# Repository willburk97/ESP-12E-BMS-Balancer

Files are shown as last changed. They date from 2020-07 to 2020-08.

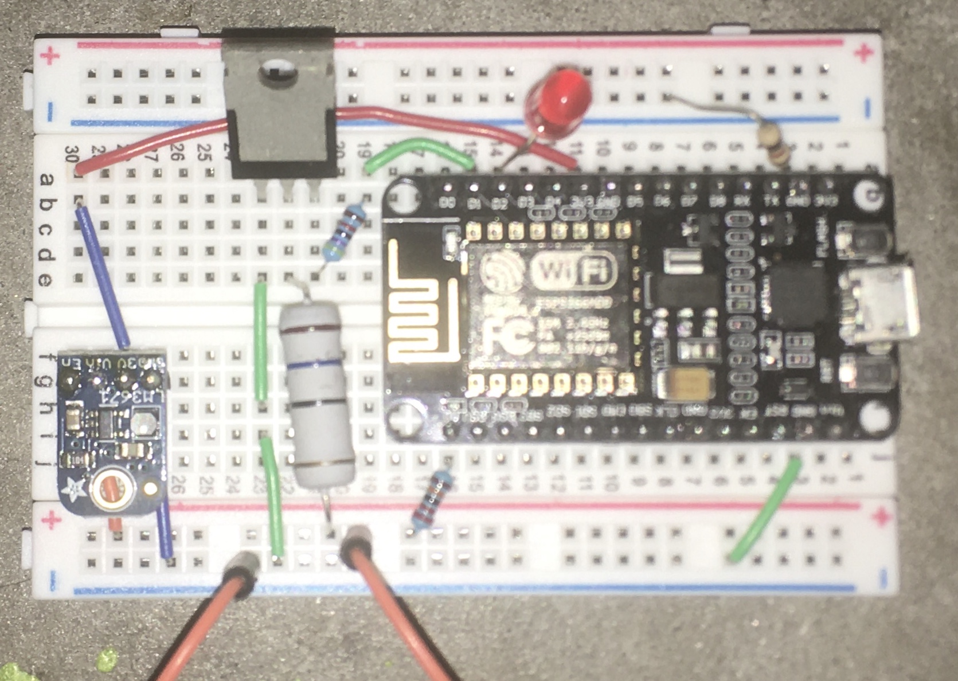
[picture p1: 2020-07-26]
DD4AA2B9-804A-49C7-B6A8-159DF102B3EF.jpeg

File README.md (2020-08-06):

# ESP-12E-BMS-Balancer
li-ion BMS / Balancer made of multiple NodeMCU ESP-12E (one per cell) using Adafruit io to store/track/trend each cell's voltage.

I used an LM3671 from adafruit to power the 3.3v in of the ESP-12E directly because my NodeMCU version uses an LDO regulator which drops half 
a volt or so. I wanted my ESP-12E to be able to continue monitoring the cell all the way down to 2.4 volts or so. The LDO wouldn't allow that.

I used an IRFZ44 mosfet (driven by D1 through a resistor) to connect a 16 ohm / 3W resistor to the batery input.  At a ~4VDC input this'd be 250mA and 1W worth of drain.  
The code leads to a battery drain (mosfet) duty cycle of about 80%, so technically about 800mW of drain.  While draining, the resistor can be touched momentarily but is 
hot enough to burn you.  It was not hot enough to melt my temporary breadboard or the wires/components nearby.

As mentioned in the code, A0 on the NodeMCU has a built in voltage divider of 100k:220k ohms.  This enables you to simply jumper from A0 to the battery in with a 220k 
resistor (for li-ion) which creates a 100k:440k voltage divider, which is a ratio of 1:5.4 

In case the search function checks the readme for codewords, here're some:
NodeMCU, ESP12, ESP-12, ESP12E, ESP-12E, ESP8266, Battery Management System, Balance, lithium, pack

I added the code from an ESP32 I was testing as well.  I coded it to monitor battery4 (and the code would have to be adjusted to match the battery it is connected to.)
This code was used before I added the staleData code you'll see in the ESP12 code.  The side effect of not having the staleData code is that if a battery is low and then
disconnected from the internet, this ESP will attempt to drain it's battery down to that last known voltage...ignoring the fact that the last known voltage could be very
very old.  This is handy for testing and/or forcing a single cell to a certain voltage but not ideal for regular use or as a reliable BMS. (Basically, I think the staleData
code is important, I just never implemented it in the ESP32 code.)

Added Schematic and Board layouts for two different ESP-12E BMS styles. One with the LM3671 from Adafruit and one without.  It can be used without the Adafruit board, but
somewhere around 3.0v the ESP-12E will turn off because of the inherent voltage drop across the LDO voltage regulator. The 'Low Voltage' version uses the Adafruit buck
converter, the other does not.  

I haven NOT double checked the schematic for accuracy nor have I printed the PCB to test it out.  Please sanity check them both before use.
I used Autodesk Eagle for the schematic and board layout.

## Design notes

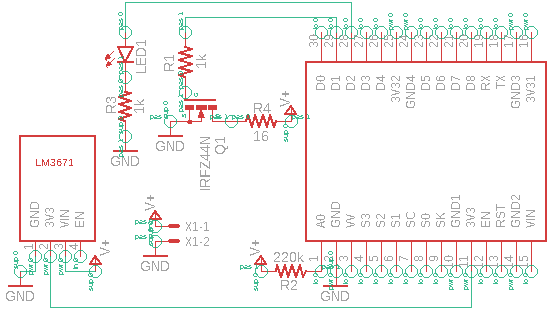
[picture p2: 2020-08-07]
ESP12E BMS Low Voltage Schematic.png

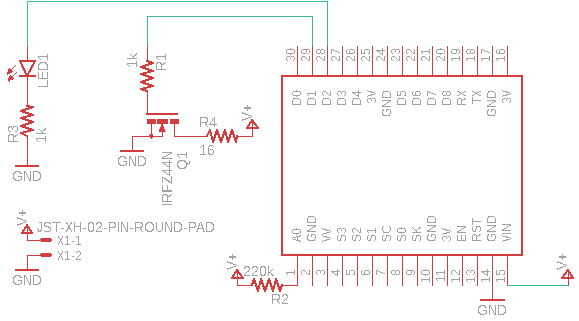
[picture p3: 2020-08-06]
ESP12E_BMS.png

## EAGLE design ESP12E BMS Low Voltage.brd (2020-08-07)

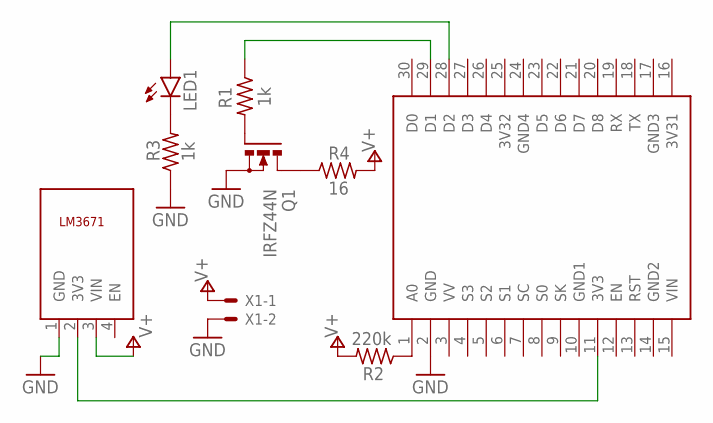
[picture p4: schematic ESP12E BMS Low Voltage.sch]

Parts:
LED1: TLLR4400; LED3MM
Q1: IRFZ44N; TO220BH
R1, R3: 1k; 0204/7
R2: 220k; 0204/7
R4: 16; P0613/15
U$1: NODEMCU
U$2: LM3671
X1: JST-XH-02-PIN-ROUND-PAD; JST-XH-02-PACKAGE-ROUND-PAD

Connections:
3V31: U$1.16 (3V31)
3V32: U$1.25 (3V32)
GND: Q1.S, R3.1, U$1.2 (GND), U$2.1 (GND), X1.2
GND1: U$1.10 (GND1)
GND2: U$1.14 (GND2)
GND3: U$1.17 (GND3)
GND4: U$1.24 (GND4)
unnamed: LED1.K (C), R3.2
unnamed: Q1.G, R1.2
unnamed: Q1.D, R4.1
unnamed: R1.1, U$1.29 (D1)
unnamed: LED1.A, U$1.28 (D2)
unnamed: R2.1, U$1.1 (A0)
unnamed: U$1.11 (3V3), U$2.2 (3V3)
V+: R2.2, R4.2, U$2.3 (VIN), X1.1

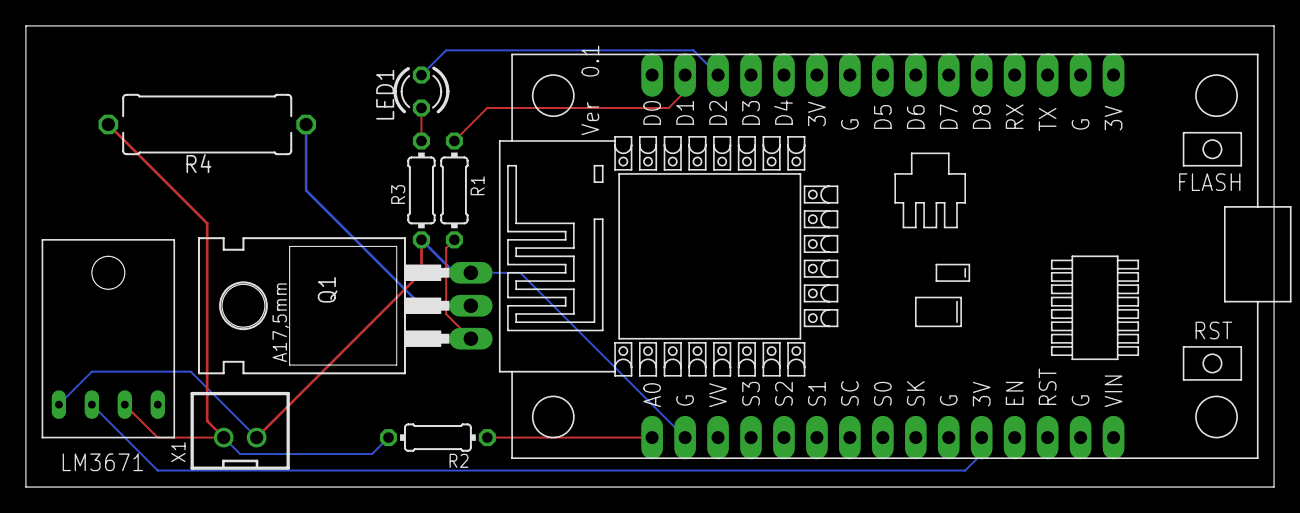
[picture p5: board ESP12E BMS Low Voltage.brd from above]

Board: 2 copper layers, 96.2 x 35.5 mm, 9 parts (0 on the bottom side), 9 nets.

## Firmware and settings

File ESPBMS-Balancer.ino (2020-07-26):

// Tutorial Link: https://learn.adafruit.com/adafruit-io-basics-analog-input
//
// Adafruit invests time and resources providing (...a small part of...) this open source code.
// Please support Adafruit and open source hardware by purchasing
// products from Adafruit!
//
// (The adafruit io portion of this was...) Written by Todd Treece for Adafruit Industries
// Copyright (c) 2016 Adafruit Industries
// Licensed under the MIT license.
//
// All text above must be included in any redistribution.

// All other code below was written by William Burk for himself or copied and pasted from somewhere else. (Sorry Todd for making a mess of your code.)


#define IO_USERNAME "Your adafruit username here"
#define IO_KEY "your adafruit key here"
#define WIFI_SSID "yourSSID"
#define WIFI_PASS "yourwifipassword"
#include "AdafruitIO_WiFi.h"
AdafruitIO_WiFi io(IO_USERNAME, IO_KEY, WIFI_SSID, WIFI_PASS);

#define analogIn A0  // The NodeMCU ESP12 has a built in 100k:220k Voltage divider so I just jumpered A0 to my battery input with a 220k resistor so it's a 1:5.4 ratio.
      // Note: Vin on the NodeMCU uses a LDO voltage regulator which wouldn't allow me to drain (or use) my battery as low as I wanted. So I ended up using the adafruit
      // LM3671 3.3v buck converter and feeding the 3.3 input on the NodeMCU directly.
#define LEDPin D0    //This is the builtin LED on the NodeMCU, it monitors communications.  On at first and then intermittent flash for comms.
#define mosfetPin D1  // This goes high to activate the mosfet (IRFZ44N) I use to discharge the battery through a 16ohm/3w resistor (4.0v li-ion, 250mA, 1 W drain)
#define dischargeLEDpin D2  //This LED shows me when the battery is being drained
float sensorValue = 0;
float allowedCellDiff = 0.05;
float lowBatt = 10;
bool dischargeState = false;
int sensorInt;
unsigned long lastTxTime = 0;

int thisBatt = 1;   // 0 referenced number of the cell this ESP12 is monitoring. This code is for cell 2.

// You have to manually change the code for each cell in the 'pack.' (This is cell 2 so we're not monitoring it's time.)
unsigned long battTime;
//unsigned long battTime2;
unsigned long battTime3;
unsigned long battTime4;

int staleData = 0;  // Binary coded stale data monitor. 0000 means current data. 0100 means Cell 3 is stale. (i.e. no updates getting to/from adafruit io)


unsigned int minTxTime = 60000;
unsigned int sampleTime = 1000;
String debugText = "0.00 0.00 0.00 0.00 ";
unsigned int dischargeTime = 0;
int i;
float battVolt[4];

AdafruitIO_Feed *espbattery = io.feed("espbattery");
AdafruitIO_Feed *espbattery2 = io.feed("espbattery2");
AdafruitIO_Feed *espbattery3 = io.feed("espbattery3");
AdafruitIO_Feed *espbattery4 = io.feed("espbattery4");
//AdafruitIO_Feed *debugtext = io.feed("debug-text");  // Activate this on one ESP12 and you'll have a quick text reference for each cell voltage.

// **You have to manually change the code for each cell in the 'pack.' (This is cell 2 so we upload it's draining status.) You only have to adjust what's in quotes.
AdafruitIO_Feed *battdischarge = io.feed("battdischarge2");

//AdafruitIO_Feed *battdischargetime = io.feed("battdischargetime2");   // This would enable us to monitor how much a cell has been drained. I turned it off to minimize updates to adafruit io.
// The above must be updated to mactch the cell connected to this ESP12.

void setup() {
  pinMode(LEDPin, OUTPUT);
  pinMode(mosfetPin, OUTPUT);
  pinMode(dischargeLEDpin, OUTPUT);
  // start the serial connection
  Serial.begin(115200);

  // connect to io.adafruit.com
  Serial.print("Connecting to Adafruit IO");
  io.connect();

  // wait for a connection
  while(io.status() < AIO_CONNECTED) {
    Serial.print(".");
    delay(500);
  }

  // we are connected
  Serial.println();
  Serial.println(io.statusText());

// You have to manually change the code for each cell in the 'pack.' (This is cell 2 so we're not requesting it's voltage from adafruit.)
  espbattery->onMessage(getBatt);
//  espbattery2->onMessage(getBatt2);
  espbattery3->onMessage(getBatt3);
  espbattery4->onMessage(getBatt4);

//These force an initial update from adafruit io.
  espbattery->get();
//  espbattery2->get();
  espbattery3->get();
  espbattery4->get();
}

void loop() {
  io.run();

  updateVoltage();

  lowBatt = 10;
  for (i=0;i<4;i++) {
    if (battVolt[i] < lowBatt) { lowBatt = battVolt[i]; }
  }

  digitalWrite(LEDPin, LOW);
  delay(30);
  digitalWrite(LEDPin, HIGH);
  
      debugText = "";
      for (i=0;i<4;i=i+1) {
        Serial.print(battVolt[i]); Serial.print(" ");
        debugText += String(battVolt[i]);
        debugText += String(" ");
      }
      Serial.println();
  if(millis() > lastTxTime + minTxTime)
  {
    lastTxTime = millis();
    Serial.println("Sent Last");

    if (battVolt[thisBatt] <= lowBatt || battVolt[thisBatt] < 3.0) {
      digitalWrite(mosfetPin, false);
      digitalWrite(dischargeLEDpin, false);
      dischargeState = false;
      Serial.println("Battery not Draining");
    }
    
// You have to manually change the code for each cell in the 'pack.' (This is cell 2 so we save it's voltage to adafruit io.)
    espbattery2->save(sensorValue);
//Enable this on one ESP12 for easy text readable battery voltages on adafruit io.    
//    debugtext->save(debugText);
//The two below are actually universal and don't have to be updated based on cell.
    battdischarge->save(dischargeState);
//    battdischargetime->save(dischargeTime);   // If you have the adafruit io bandwidth this is a nice way to keep track of each cells drain time.  The cell with the lowest time is the weakest.
    
    digitalWrite(LEDPin, LOW);
    delay(100); // just to be safe

// I originally used these to force a read of the adafruit io every tx loop. These are unnecessary since the onMessage code gives us the updates as soon as adafruit io gets them. 
// Note: You cannot use these if you want the battTime code to work as these force the battTime to update every time they're run. (And these just load whatever old data exists.)
//    espbattery->get();
//    espbattery2->get();
//    espbattery3->get();
//    espbattery4->get();

    digitalWrite(LEDPin, HIGH);

  }
    
  if (dischargeState) { dischargeTime++; }
  
  if ((millis() > 30000) && (battVolt[thisBatt] > (lowBatt + allowedCellDiff)) && (battVolt[thisBatt] > 3.0) && (staleData == 0)) {
    digitalWrite(mosfetPin, true);
    digitalWrite(dischargeLEDpin, true);
    dischargeState = true;
    Serial.println("Battery Draining");
  }
  
  delay(sampleTime-150);

}

void updateVoltage() {

  digitalWrite(mosfetPin, false);  // Turn off the mosfet/resistor load so we can read an accurate 'unloaded' voltage.
  
  int sensorInt = 0;
  for (i=0;i<10;i=i+1) {
    delay(15);
    sensorInt = sensorInt + analogRead(analogIn);
  }
  sensorInt = sensorInt / 10;
  sensorValue = (sensorInt * 5.44) / 1024;  //was 5.31
  sensorInt = (sensorValue * 100);     // Round to two decimal places...
  sensorValue = sensorInt;
  sensorValue = sensorValue / 100;
  
  battVolt[thisBatt] = sensorValue;
  
// ***You have to manually change the code for each cell in the 'pack.' (This is cell 2 so we're not monitoring it's staleness/time.)
  if ((battTime + 80000) < millis()){ staleData = (staleData | (0x1));  }
//  if ((battTime2 + 80000) < millis()){ staleData = (staleData | (0x2));  }
  if ((battTime3 + 80000) < millis()){ staleData = (staleData | (0x4));  }
  if ((battTime4 + 80000) < millis()){ staleData = (staleData | (0x8));  }

  Serial.println(staleData,BIN);
  if (staleData > 0) {
    dischargeState = false;
    digitalWrite(dischargeLEDpin, false);
    delay(300);
    digitalWrite(dischargeLEDpin, true);
  }
  digitalWrite(mosfetPin, dischargeState);
}

// ***You have to manually change the code for each cell in the 'pack.' (This is cell 2 so we're not monitoring it's time.) Commenting this out may(shoud?) be unnecessary.
void getBatt(AdafruitIO_Data *data) {
  battVolt[0] = data->toFloat();
  battTime = millis();
  staleData = (staleData & (0xF - 0x1));
}
//void getBatt2(AdafruitIO_Data *data) {
//  battVolt[1] = data->toFloat();
//  battTime2 = millis();
//  staleData = (staleData & (0xF - 0x2));
//}
void getBatt3(AdafruitIO_Data *data) {
  battVolt[2] = data->toFloat();
  battTime3 = millis();
  staleData = (staleData & (0xF - 0x4));
}
void getBatt4(AdafruitIO_Data *data) {
  battVolt[3] = data->toFloat();
  battTime4 = millis();
  staleData = (staleData & (0xF - 0x8));
}

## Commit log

2020-07-26 Add files via upload
    Details are within the code. I hope to tweak the code so it's easier to configure for each cell. Currently, you'll have to change the code before you upload it to match the cell. (I.e. correct the code for cell 1, upload to ESP-12E #1. Correct the code for Cell 2 then upload to ESP-12E #2.) Note: This code only manages battery voltage uploading (to adafrutit io) and battery balancing. One of the ESP-12E's should have code added to control the overall load (or charger) itself. When any cell goes below (or above) a set value you need to turn off the load (or the charger).
    [ESPBMS-Balancer.ino]
2020-07-28 Add files via upload
    Adding draft ESP32 code.
2020-08-06 Update README.md
    Added notes about recently added schematics and boards.
